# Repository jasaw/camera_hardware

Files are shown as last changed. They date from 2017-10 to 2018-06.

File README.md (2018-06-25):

# Raspberry Pi based security camera hardware

Outdoor Raspberry Pi Zero W security camera
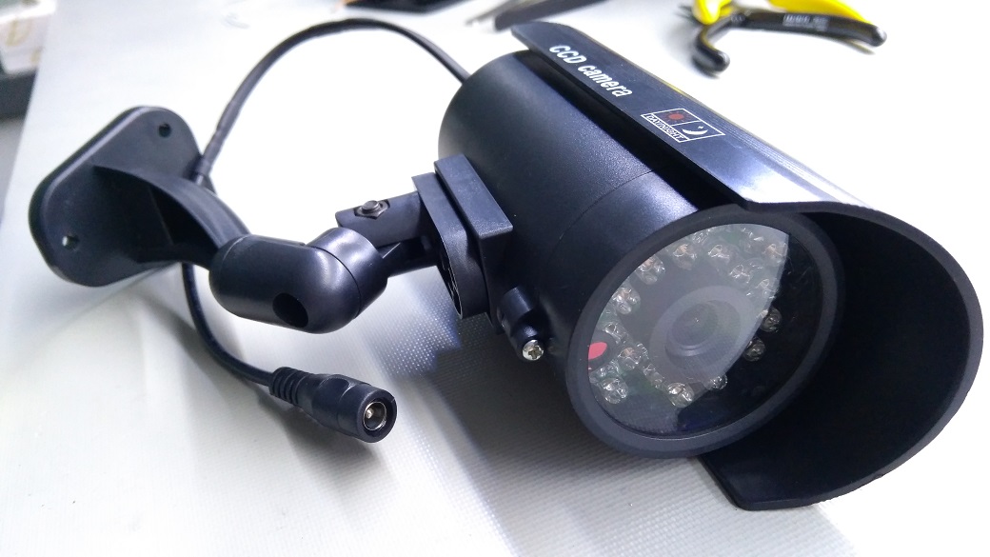
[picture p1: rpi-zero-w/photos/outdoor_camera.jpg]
outdoor_rpi_zero_w_cam


## Software

If you don't already have software to run on this camera, [motionEyeOS](https://github.com/jasaw/motioneyeos/releases) is a good one to try.

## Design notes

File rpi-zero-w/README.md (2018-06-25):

# Raspberry Pi Zero W security camera hardware

Outdoor Raspberry Pi Zero W security camera
outdoor_rpi_zero_w_cam

Exploded view of the camera parts.
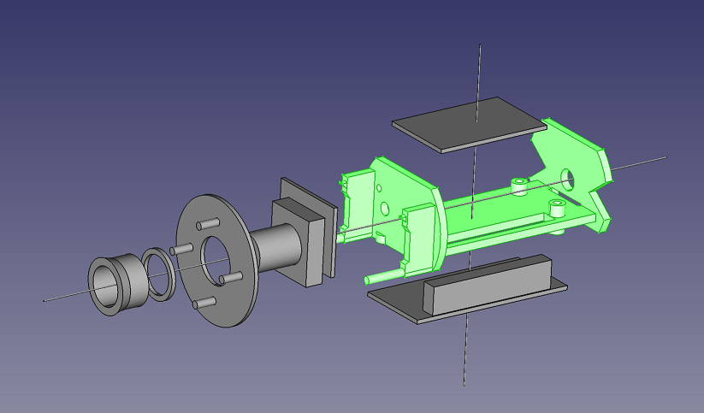
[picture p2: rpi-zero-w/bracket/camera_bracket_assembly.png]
assembly


## Bill of Materials

* Outdoor dummy security camera:
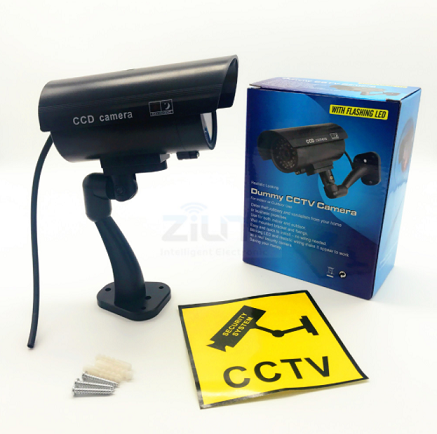
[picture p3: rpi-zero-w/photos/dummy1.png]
dummy1
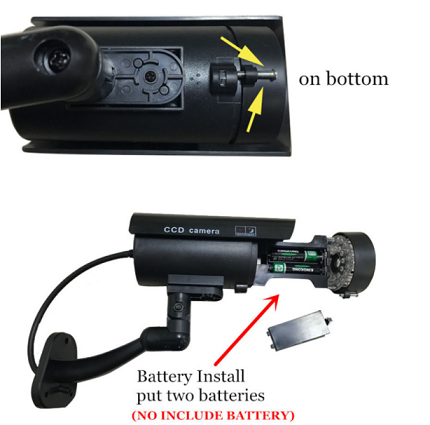
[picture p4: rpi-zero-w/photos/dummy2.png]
dummy2
  * 
  * Brand: zilnk
  * Model: D4
  * External dimensions: 117 x 117 x 65 mm
  * Internal dimensions: 103 x 48 mm
  * [AliExpress](https://www.aliexpress.com/item/Fake-Camera-Waterproof-Outdoor-Indoor-Security-Dummy-CCTV-Surveillance-Camera-Flashing-Rred-LED/32815686364.html)

* 3D printed camera bracket:
  * [Camera mounting bracket](bracket/README.md)

* 3D printed camera shroud:
  * [Camera shroud](bracket/camera_shroud.stl)

* 1.6mm foam tape

* Raspberry Pi NoIR Camera with IR-cut filter:
  * [AliExpress](https://www.aliexpress.com/item/Raspberry-Pi-Camera-IR-CUT-night-vision-noir-module-board-5mp-1080p-take-the-best-picture/32739395193.html)

* Raspberry Pi Zero camera FFC cable
  * [ebay](http://www.ebay.com.au/itm/New-Ribbon-FFC-Cable-Lead-Connection-Wire-For-Raspberry-Pi-Zero-V1-3-Camera/182720702738)
  * [ebay](http://www.ebay.com.au/itm/New-Ribbon-FFC-Cable-Wire-Line-Polyimide-For-Raspberry-Pi-Zero-V1-3-Camera/282571229898)

* Raspberry Pi Zero W without header

* 40-pin 0.1" pitch header for Raspberry Pi Zero W
  * Manufacturer part number: PREC020DAAN-RC
  * Digikey part number: S2012EC-20-ND
  * Alternate part number: PRPC020DAAN-RC

* microSD card

* Raspberry Pi Zero W PSU PCBA
  * [RPi Zero power supply PCBA](rpi-zero-psu/README.md)

* Camera IR-LED board
  * [IR-LED PCBA](camera-ir-led/README.md)

* 10cm 22AWG Male Female Connector JST Cable
    * [AliExpress](https://www.aliexpress.com/item/10-Pairs-100mm-10cm-Male-Female-Connector-JST-Plug-Cable-For-RC-BEC-Battery-Helicopter-DIY/32823944800.html)

* 12V DC Female Jack Connector Cable 5.5 X 2.1mm With 15CM Cable
    * [AliExpress](https://www.aliexpress.com/item/10pcs-12V-DC-Power-Plug-Female-Jack-Plug-Connector-Cable-5-5X2-1mm-With-Cord-Cable/32536715262.html)

* Minimum 12V 1A DC power supply with barrel connector
  * Barrel size: 5.5 x 2.1mm
  * [Jaycar - 12V DC 2.5A](https://www.jaycar.com.au/switchmode-mains-adaptor-12vdc-2-5a/p/MP3490)
  * [Little Bird Electronics - 12V DC 2.5A](https://www.littlebirdelectronics.com.au/switchmode-mains-adaptor-12vdc-2.5a)
  * [AliExpress - 12V DC power supply AU](https://www.aliexpress.com/item/Led-transformer-AC-110V-220V-to-12V-DC-EU-US-UK-AU-plug-Power-supply-12V/32702717419.html)
  * [AliExpress - 12V DC power supply AU](https://www.aliexpress.com/item/Power-Adapter-Supply-For-Led-Flexible-Tape-Light-AC110-220V-to-DC12V-1A-2A-3A-4A/32742445815.html)
  * [AliExpress - 12V DC power supply AU](https://www.aliexpress.com/item/LED-Driver-12V-1A-2A-3A-5A-6A-8A-10A-Power-Supply-AC-220V-to-12V/32821553829.html)

* 2 x 16mm M2.5 screws
  * [AliExpress](https://www.aliexpress.com/item/Cheap-Authentic-304-stainless-steel-Phillips-head-machine-screw-Phillips-pan-head-screws-M2-5-16/32368120946.html)

* 2 x M2.5 hex nuts
  * [AliExpress](https://www.aliexpress.com/item/Authentic-304-stainless-steel-hex-nuts-DIN934-hexagon-nut-M2-5/32359608962.html)

* 2 x 8mm M2 screws
  * [AliExpress](https://www.aliexpress.com/item/100PCS-Stainless-Steel-M2-x-8mm-Screw-Cross-Round-Head-Philips-Head-Screws-Hex-Socket-Button/32716321685.html)
  * [AliExpress](https://www.aliexpress.com/item/50x-Set-M2-Stainless-Steel-Screw-Thread-Diameter-304-8mm-2mm-Head-Shape-Cross-Screws-Round/32598285502.html)

* 2 x M2 hex nuts
  * [AliExpress](https://www.aliexpress.com/item/100pcs-din934-Stainless-Steel-304-M2-Hex-Nut/32763090222.html)

* (optional) 5.5*2.1mm DC 1 To 2 Way Jack Connector Power Splitter Cable
  * [AliExpress](https://www.aliexpress.com/item/2pcs-5-5-2-1mm-DC-1-To-2-Way-Jack-Connector-Power-Splitter-Cable-For/32845687591.html)

## Assembly Instructions

[Assembly instructions](README_assembly.md)

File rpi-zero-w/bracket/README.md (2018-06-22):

# 3D printed mounting bracket & camera shroud

3D printed mounting bracket for dummy camera enclosure. Only works with this [outdoor dummy camera](https://www.aliexpress.com/item/Fake-Camera-Waterproof-Outdoor-Indoor-Security-Dummy-CCTV-Surveillance-Camera-Flashing-Rred-LED/32815686364.html) enclosure.

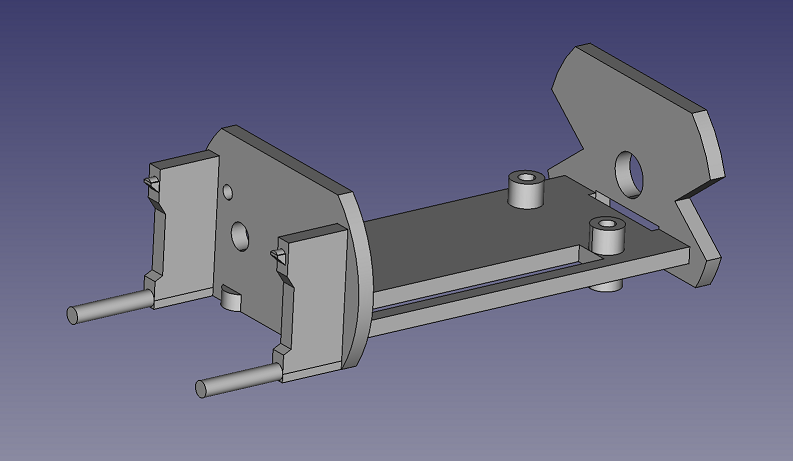
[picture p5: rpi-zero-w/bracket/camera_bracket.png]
bracket


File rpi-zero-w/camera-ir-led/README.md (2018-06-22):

# IR-LED board

IR-LED board for night vision.

Current issues:
* IR light is not bright enough to illuminate large area
  * As a workaround, use [external IR LEDs](https://www.aliexpress.com/item/Free-shipping-48LEDs-Illuminator-IR-Infrared-dome-CCTV-camera-hd-Night-enhancement-Fill-light-Vision-40M/32811672765.html).

### Design files

* [Gerbers](camera-ir-led-rev-1a.zip)
* [PCB top](camera-ir-led-rev-1a-top-parts.pdf)
* [PCB bottom](camera-ir-led-rev-1a-bottom-parts.pdf)

### Bill of Materials

* [BoM](camera-ir-led-rev-1a.xlsx)
* 5mm IR LEDs 940nm Wave Length
  * Forward Voltage: 1.5~1.6V
  * Forward Current: 60mA Continuous, 120mA peak 10% pulse width
  * View Angle: 15-30 degree
  * [ebay](https://www.ebay.com.au/itm/100pcs-5mm-LED-Lights-Infrared-Emitters-IR-Emitting-Diodes-940nm-Wave-Length/201201649166)
* 5mm IR LEDs 850nm Wave Length
  * Forward Voltage: 1.45~1.65V
  * Forward Current: 20mA Continuous, 100mA max pulse
  * View Angle: 30 degree
  * [AliExpress](https://www.aliexpress.com/item/100Pcs-5mm-IR-Led-850nm-Lamp-Transmitting-Tube-Emitting-Diode-Infrared-LED-Diode-ir-850nm-High/32373548361.html)
* GL5528 LDR Photo Resistors
  * [ebay](http://www.ebay.com.au/itm/20PCS-Photoresistor-GL5528-LDR-Photo-Resistors-Light-Dependent-WS/222122787897)
* JST PH 2.00mm pitch 4-pin connector and cable
  * [AliExpress](https://www.aliexpress.com/item/20-Sets-PH-2-0mm-JST-2-3-4-5-6-7-8-9-10-12P/32782287584.html)
  * [AliExpress](https://www.aliexpress.com/item/20-SETS-Mini-Micro-JST-2-0-PH-4-Pin-Connector-plug-with-Wires-Cables-300MM/32611300648.html)
  * [AliExpress](https://www.aliexpress.com/item/10sets-1-0mm-1-25mm-1-5mm-2-0-2-54mm-2-3-4-5-6/32733307616.html)
* Optical IR Cut Light Filter 8mm (for LDR light sensor)
  * [ebay](https://www.ebay.com.au/itm/10pcs-Optical-UV-IR-Cut-Light-Filter-Blocking-For-Camera-Astronomy-Lens-8mm-Slim/282653207704)
* Some heatshrink to hold the IR Cut Light Filter

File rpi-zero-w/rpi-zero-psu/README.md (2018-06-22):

# Raspberry Pi Zero power supply

Power supply board that plugs directly onto a Raspberry Pi Zero (W)

Features:
* Input: 9V to 24V DC
* Output: 5V 3A to the RPi
* Basic light sensor circuit ([LDR reader software here](https://github.com/jasaw/ldr-reader))
* One GPIO controlled output (5V 1A)

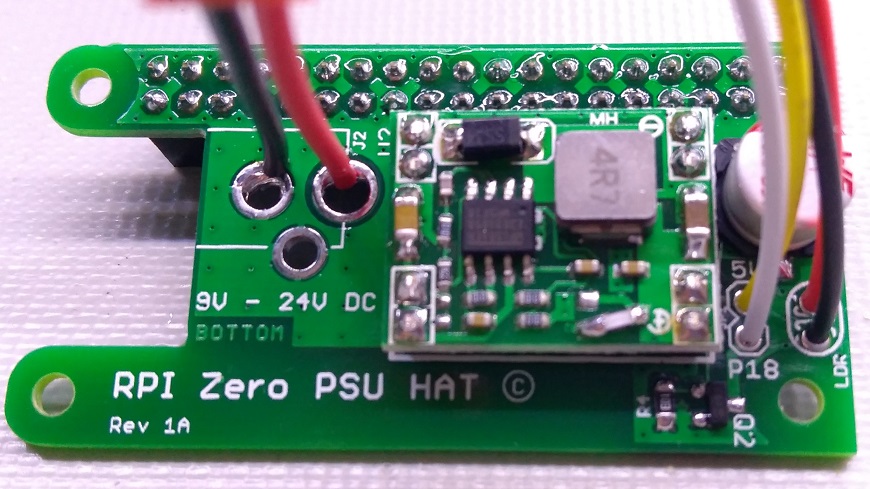
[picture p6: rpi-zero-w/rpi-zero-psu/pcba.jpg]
PCBA


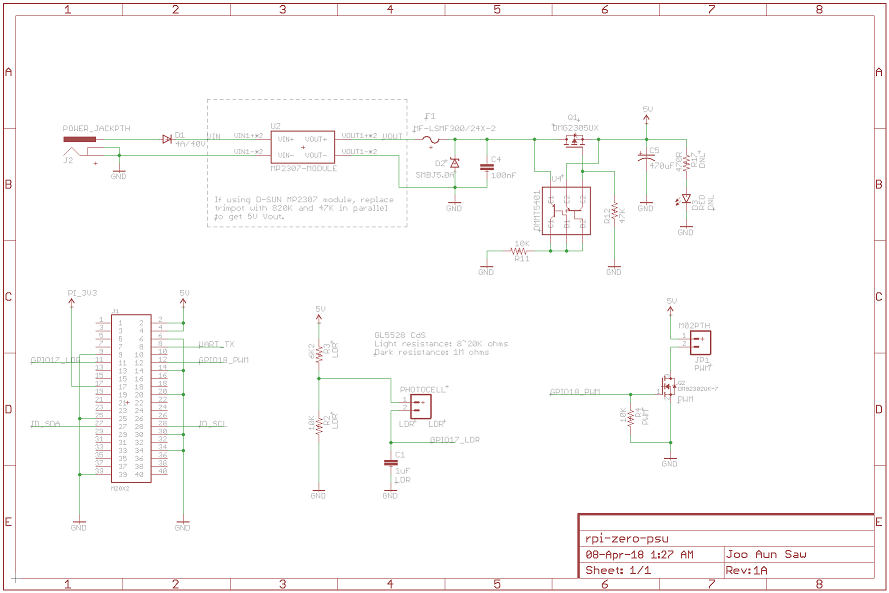
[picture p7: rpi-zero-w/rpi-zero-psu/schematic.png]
schematic


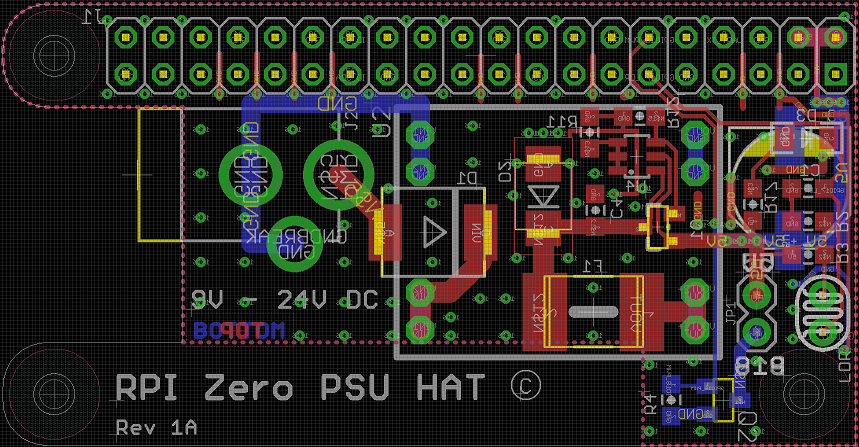
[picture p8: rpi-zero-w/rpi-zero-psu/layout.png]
layout


### Design files

* [Gerbers](rpi-zero-psu-rev-1a.zip)
* [PCB top](rpi-zero-psu-rev-1a-top.pdf)
* [PCB bottom](rpi-zero-psu-rev-1a-bottom.pdf)

### Bill of Materials

* [BoM](rpi-zero-psu-rev-1a-bom.pdf)
* 3A XM1584 DC-DC step-down module can be sourced from other places:
  * [Seeed Studio](https://www.seeedstudio.com/Adjustable-Step-Down-DC%26DC-Converter-%280.8V-18V%263A%29-p-1716.html)
  * [AliExpress](https://www.aliexpress.com/item/Free-Shipping-5PCS-XM1584-Ultra-small-size-DC-DC-step-down-power-supply-module-3A-adjustable/32262690691.html)
  * [AliExpress](https://www.aliexpress.com/item/10pcs-lot-Ultra-Small-Size-DC-DC-Step-Down-Power-Supply-Module-3A-Adjustable-Step-Down/32478748937.html)

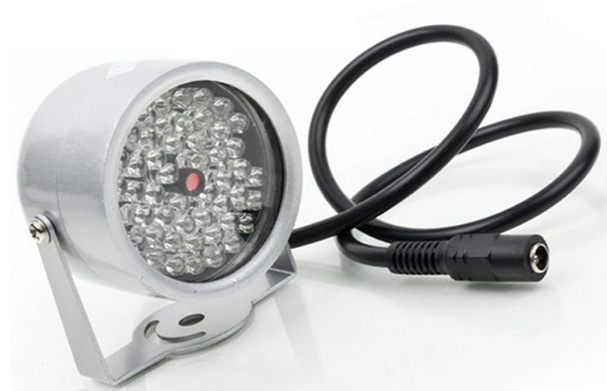
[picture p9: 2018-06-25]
rpi-zero-w/photos/external_ir_led.png

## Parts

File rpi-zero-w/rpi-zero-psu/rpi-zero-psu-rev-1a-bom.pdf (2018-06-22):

Qty Value | Parts | Description | DIGIKEY | MOUSER | PARTNO
1 DMG2302UK-7 | Q2 | N-Channel Mosfet | DMG2302UK-7DICT-ND | 621-DMG2302UK-7 | DMG2302UK-7
1 100nF | C4 | Capacitor | 478-1395-1-ND | 581-08055C104K | 08055C104KAT2A
1 10K | R2 | Resistor | 311-10KARCT-ND | 603-RC0805JR-0710KL | RC0805JR-0710KL
1 10K | R4 | Resistor | 311-10KARCT-ND | 603-RC0805JR-0710KL | RC0805JR-0710KL
1 10K | R11 | Resistor | 311-10KARCT-ND | 603-RC0805JR-0710KL | RC0805JR-0710KL
1 1uF | C1 | Capacitor | 311-1456-1-ND | 603-CC805KKX7R8BB105 CC0805KKX7R8BB105
1 470uF | C5 | Capacitor Polarized | 732-6443-1-ND | 710-875115150005 | 875115150005
1 47K | R12 | Resistor | 311-47.0KCRCT-ND | 603-RC0805FR-0747KL | RC0805FR-0747KL
1 4A/40V | D1 | Diode | MBRS340T3GOSCT-ND | 863-MBRS340T3G | MBRS340T3G
1 6K2 | R3 | Resistor | 311-6.2KARCT-ND | 603-RC0805JR-076K2L | RC0805JR-076K2L
1 DMG2305UX | Q1 | P-Channel Mosfet | DMG2305UX-7DICT-ND | 621-DMG2305UX-7 | DMG2305UX-7
1 DMMT5401 | U4 | Matched PNP Small Signal Transistor. DMMT5401-FDICT-ND | 621-DMMT5401-7-F | DMMT5401-7-F
1 M20X2 | J1 | 40-pin female header 0.1" pitch | S7123-ND | 517-929975-01-20 | PPPC202LFBN-RC
1 MF-LSMF300/24X-2 F1 | PTC fuse | MF-LSMF300/24X-2CT-ND 652-MF-LSMF300/24X-2 MF-LSMF300/24X-2
1 MP2307-MODULE U2 | DC-DC buck converter module | 106990005-ND | 713-106990005 | 106990005
1 POWER_JACKPTH | J2 | Power Jack | CP-002A-ND | 490-PJ-002A | PJ-002A
1 SMBJ5.0A | D2 | Zener Diode | SMBJ5.0ALFCT-ND | 576-SMBJ5.0A | SMBJ5.0A

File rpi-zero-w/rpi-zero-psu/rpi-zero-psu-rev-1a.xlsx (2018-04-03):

Qty | Value | Package | Parts | Description | DNL | LDR | PWM | DIGIKEY | MOUSER | PARTNO | ALT_PARTNO
1 | DMG2302UK-7 | SOT23 | Q2 | N-Channel Mosfet |  |  | 1 | DMG2302UK-7DICT-ND | 621-DMG2302UK-7 | DMG2302UK-7
1 | 100nF | 805 | C4 | Capacitor |  |  |  | 478-1395-1-ND | 581-08055C104K | 08055C104KAT2A
1 | 10K | 805 | R2 | Resistor |  | 1 |  | 311-10KARCT-ND | 603-RC0805JR-0710KL | RC0805JR-0710KL
1 | 10K | 805 | R4 | Resistor |  |  | 1 | 311-10KARCT-ND | 603-RC0805JR-0710KL | RC0805JR-0710KL
1 | 10K | 805 | R11 | Resistor |  |  |  | 311-10KARCT-ND | 603-RC0805JR-0710KL | RC0805JR-0710KL
1 | 1uF | 805 | C1 | Capacitor |  | 1 |  | 311-1456-1-ND | 603-CC805KKX7R8BB105 | CC0805KKX7R8BB105
1 | 470R | 805 | R17 | Resistor | 1 |  |  | 311-470ARCT-ND | 603-RC0805JR-07470RL | RC0805JR-07470RL
1 | 470uF | PANASONIC_F | C5 | Capacitor Polarized |  |  |  | 732-6443-1-ND | 710-875115150005 | 875115150005 | EEE-1CA471UP
1 | 47K | 805 | R12 | Resistor |  |  |  | 311-47.0KCRCT-ND | 603-RC0805FR-0747KL | RC0805FR-0747KL
1 | 4A/40V | SMC | D1 | Diode |  |  |  | MBRS340T3GOSCT-ND | 863-MBRS340T3G | MBRS340T3G
1 | 6K2 | 805 | R3 | Resistor |  | 1 |  | 311-6.2KARCT-ND | 603-RC0805JR-076K2L | RC0805JR-076K2L
1 | DMG2305UX | SOT-23 | Q1 | P-Channel Mosfet |  |  |  | DMG2305UX-7DICT-ND | 621-DMG2305UX-7 | DMG2305UX-7
1 | DMMT5401 | SOT23-6 | U4 | Matched PNP Small Signal Transistor. |  |  |  | DMMT5401-FDICT-ND | 621-DMMT5401-7-F | DMMT5401-7-F
1 | M02PTH | 1X02 | JP1 | Standard 2-pin 0.1 header |  |  | 1 |  | 571-826936-2 | 826936-2
1 | M20X2 | 2X20 | J1 | 40-pin female header 0.1" pitch |  |  |  | S7123-ND | 517-929975-01-20 | PPPC202LFBN-RC
1 | MF-LSMF300/24X-2 | 2920 | F1 | PTC fuse |  |  |  | MF-LSMF300/24X-2CT-ND | 652-MF-LSMF300/24X-2 | MF-LSMF300/24X-2
1 | MP2307-MODULE | MP1584EN-MODULE | U2 | DC-DC buck converter module |  |  |  | 106990005-ND | 713-106990005 | 106990005 | IM130731001
1 | PHOTOCELL | 1X02_NO_SILK | LDR | Photo resistor |  | 1 |  |  |  | GL5528
1 | POWER_JACKPTH | POWER_JACK_PTH | J2 | Power Jack |  |  |  | CP-002A-ND | 490-PJ-002A | PJ-002A
1 | RED | LED-1206 | D3 | Red LED | 1 |  |  | 160-1167-1-ND | 859-LTST-C150CKT | LTST-C150CKT
1 | SMBJ5.0A | SMB-DIODE | D2 | Zener Diode |  |  |  | SMBJ5.0ALFCT-ND | 576-SMBJ5.0A | SMBJ5.0A

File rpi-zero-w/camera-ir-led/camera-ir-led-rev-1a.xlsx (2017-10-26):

Qty | Value | Device | Package | Parts | Description | DIGIKEY | MOUSER | PARTNO
8 | 10R | RESISTOR0805-RES | 805 | R2, R3, R4, R5, R6, R7, R8, R17 | Resistor | 311-10ARCT-ND | 603-RC0805JR-0710RL | RC0805JR-0710RL
24 | IR | LED5MM | LED5MM | D1, D2, D3, D4, D5, D6, D7, D8, D9, D10, D11, D12, D13, D14, D15, D16, D17, D18, D19, D20, D21, D22, D23, D24 | LEDs
1 | JST-PH-4 | CONNECTOR-4-POS-THJST-PH-4 | JST-PH-4-POS-TH | J1 | 4-pin JST PH 2.0mm pitch
1 | PHOTOCELLPTH | PHOTOCELLPTH | PHOTOCELL | R1 | CdS photoresistor |  |  | GL5528

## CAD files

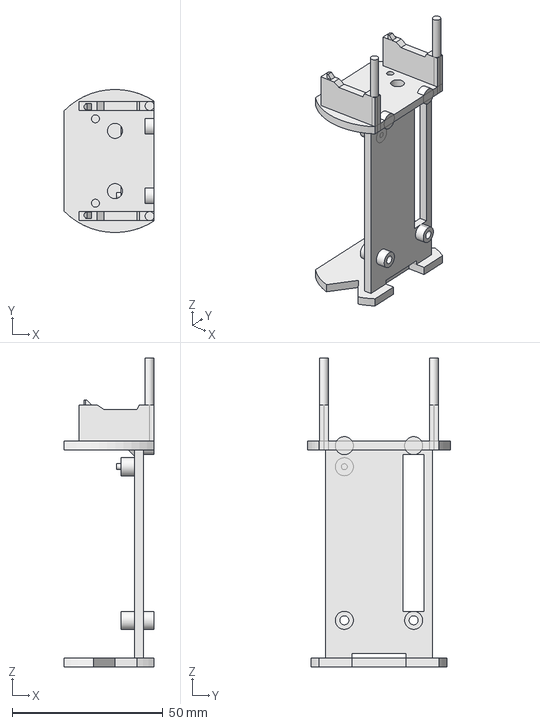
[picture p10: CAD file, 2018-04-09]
rpi-zero-w/bracket/camera_bracket.FCStd
30.0 x 47.5 x 102.6 mm

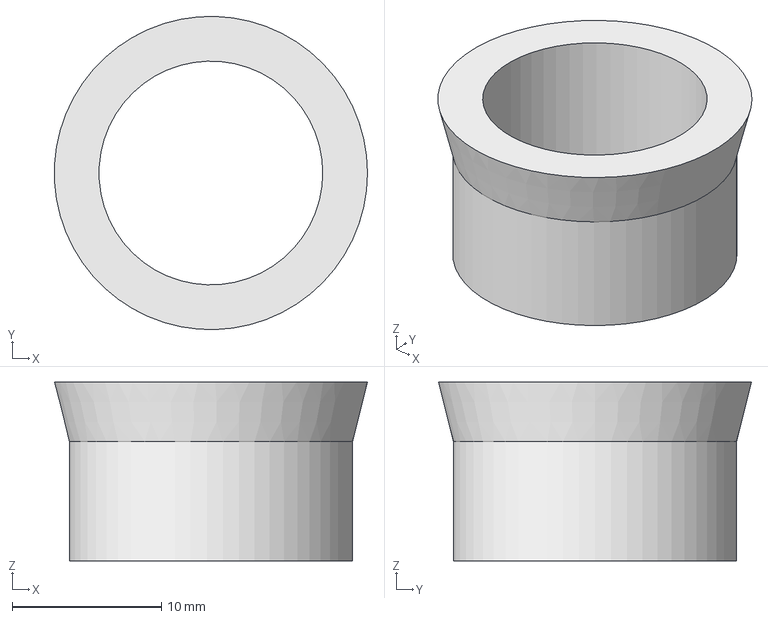
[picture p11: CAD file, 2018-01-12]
rpi-zero-w/bracket/camera_shroud.FCStd
21.0 x 21.0 x 12.0 mm

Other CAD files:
rpi-zero-w/bracket/camera_bracket.stl
rpi-zero-w/bracket/camera_shroud.stl

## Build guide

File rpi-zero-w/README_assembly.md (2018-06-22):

# Raspberry Pi Zero W security camera hardware assembly instructions

1. Solder a male 40-pin connector on the underside of the RPi Zero W.

2. Cut the foam tape into an O-ring shape and stick it at the bottom of the 3D printed camera shroud.

3. Mount the camera module onto the 3D printed bracket and secure it using two M2 screws and nuts.

4. Insert the IR-LED board.

5. Prepare all the parts required to install onto the 3D printed bracket.
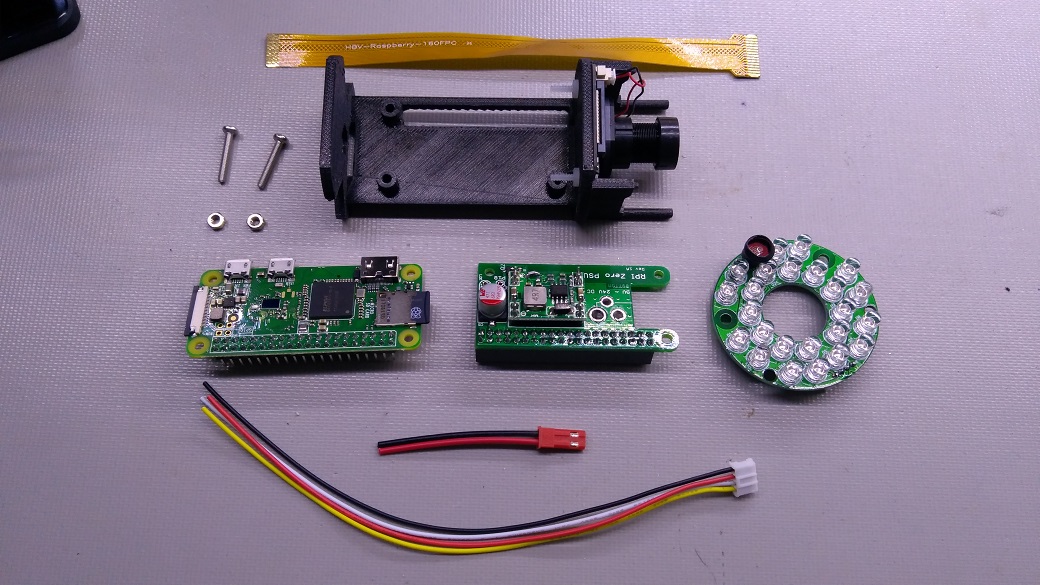
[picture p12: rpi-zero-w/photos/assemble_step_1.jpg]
step 1
   

6. Solder power cable and 4-wire cable onto the RPi Zero power supply PCBA.
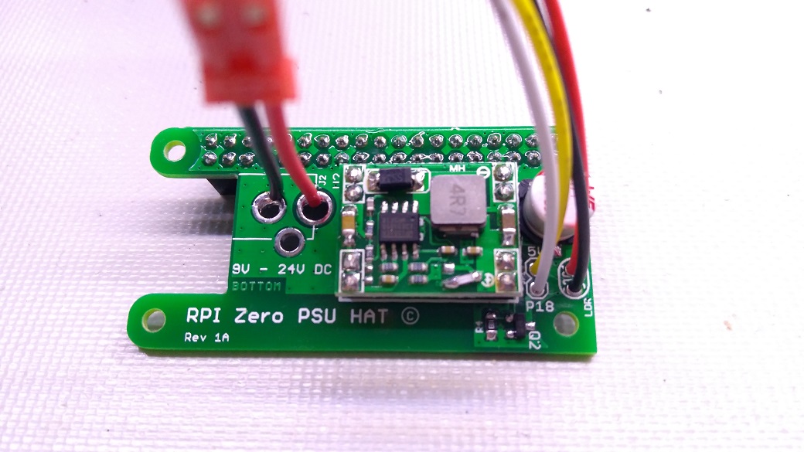
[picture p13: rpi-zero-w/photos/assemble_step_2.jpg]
step 2
   

7. Connect the FFC camera cable to the RPi Zero W and loop it through the bracket.
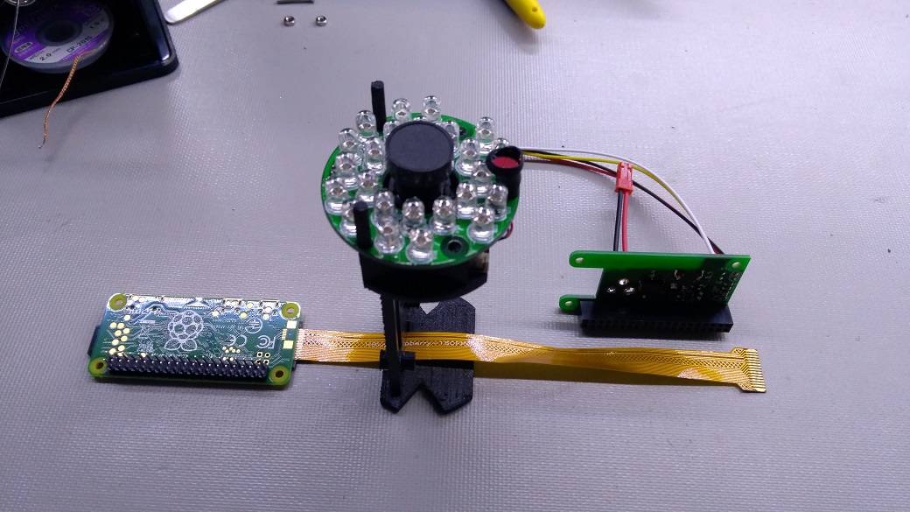
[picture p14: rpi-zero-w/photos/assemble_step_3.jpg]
step 3
   

8. Connect the FFC camera cable to the camera module. Mount the RPi Zero W and power supply PCBA together with the 3D printed bracket in between. Secure the boards using two M2.5 screws and nuts.
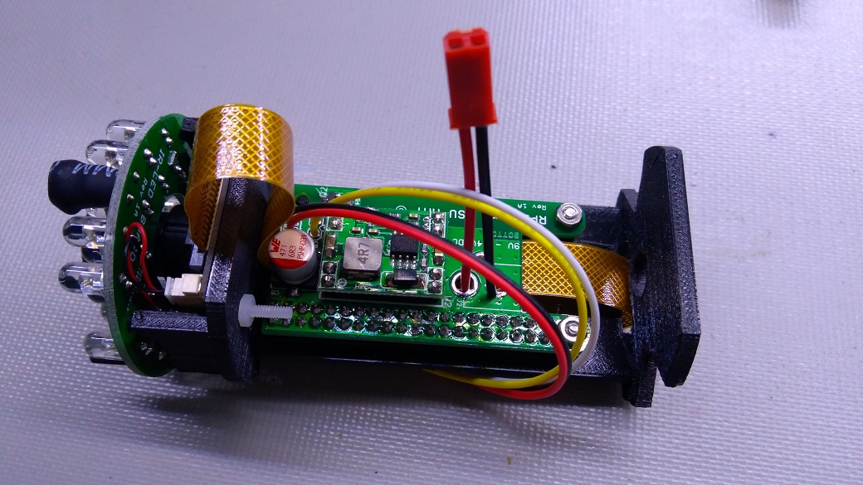
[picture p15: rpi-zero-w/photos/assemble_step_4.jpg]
step 4
   

9. Connect the 4-wire cable to the IR-LED board.
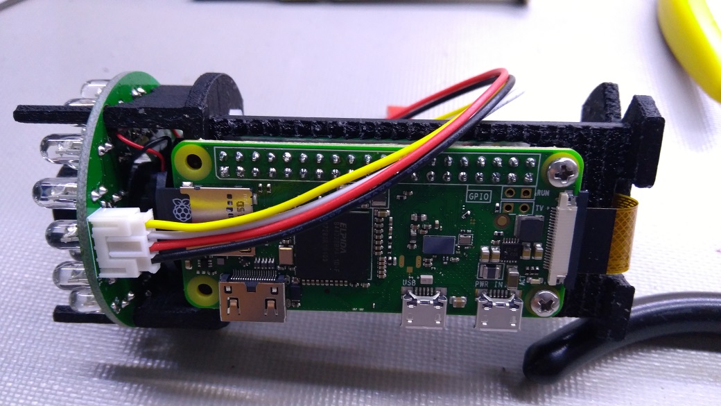
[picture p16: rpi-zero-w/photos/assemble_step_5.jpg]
step 5
   

10. Disassemble the dummy camera and prepare the cables required.
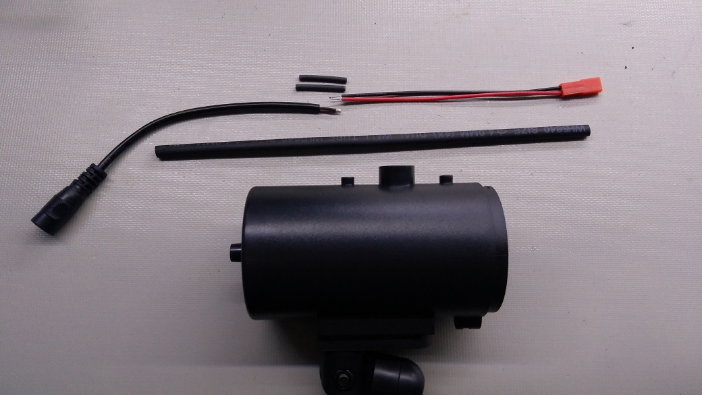
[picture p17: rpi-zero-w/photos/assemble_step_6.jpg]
step 6
    

11. Insert the heatshrink over the wires then loop the power cable through the hole at the back of the dummy camera case. Solder the power cables together and use heatshrink over the cable.
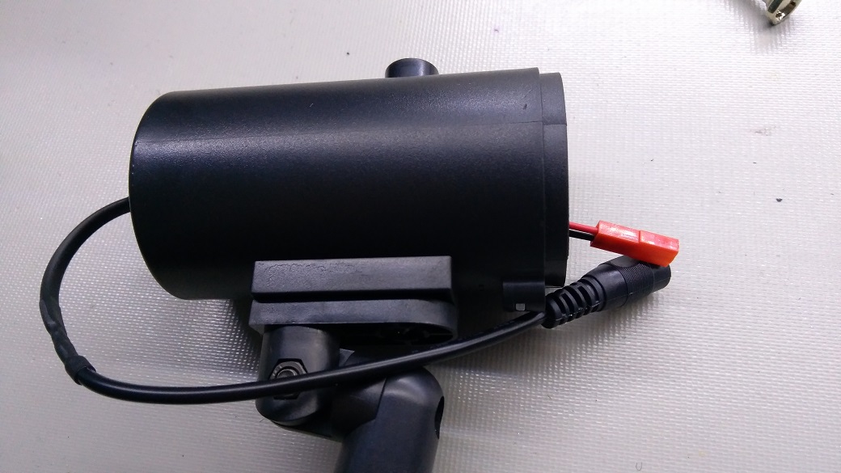
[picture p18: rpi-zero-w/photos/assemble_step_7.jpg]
step 7
    

12. Insert the assembled 3D printed bracket into the dummy camera case, insert the camera shroud, and close it. Done.
    step 8

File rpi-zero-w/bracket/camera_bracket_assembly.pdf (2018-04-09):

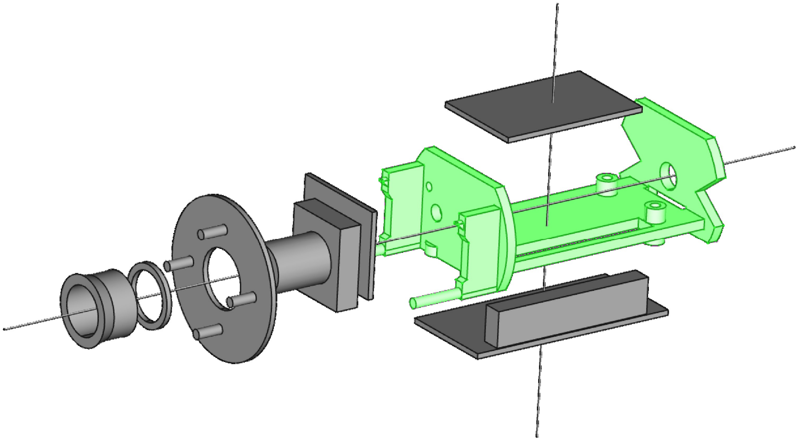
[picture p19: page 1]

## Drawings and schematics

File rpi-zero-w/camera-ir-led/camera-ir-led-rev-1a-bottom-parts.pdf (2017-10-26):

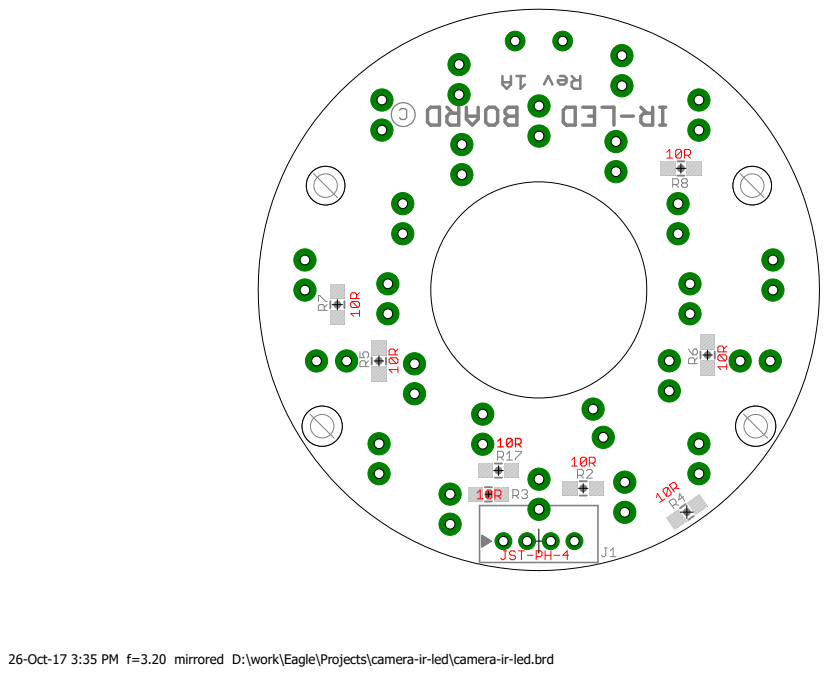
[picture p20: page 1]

26-Oct-17 3:35 PM f=3.20 mirrored D:\work\Eagle\Projects\camera-ir-led\camera-ir-led.brd

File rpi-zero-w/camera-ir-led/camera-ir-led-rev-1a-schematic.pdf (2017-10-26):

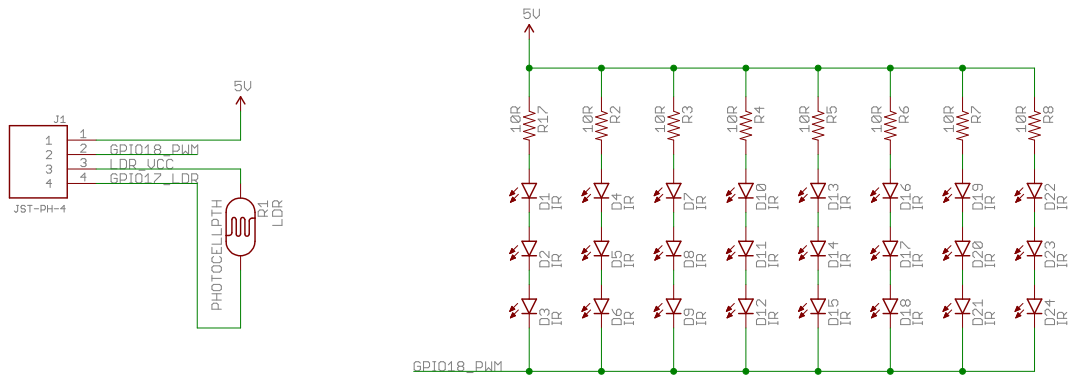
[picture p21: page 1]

26-Oct-17 3:36 PM D:\work\Eagle\Projects\camera-ir-led\camera-ir-led.sch (Sheet: 1/1)

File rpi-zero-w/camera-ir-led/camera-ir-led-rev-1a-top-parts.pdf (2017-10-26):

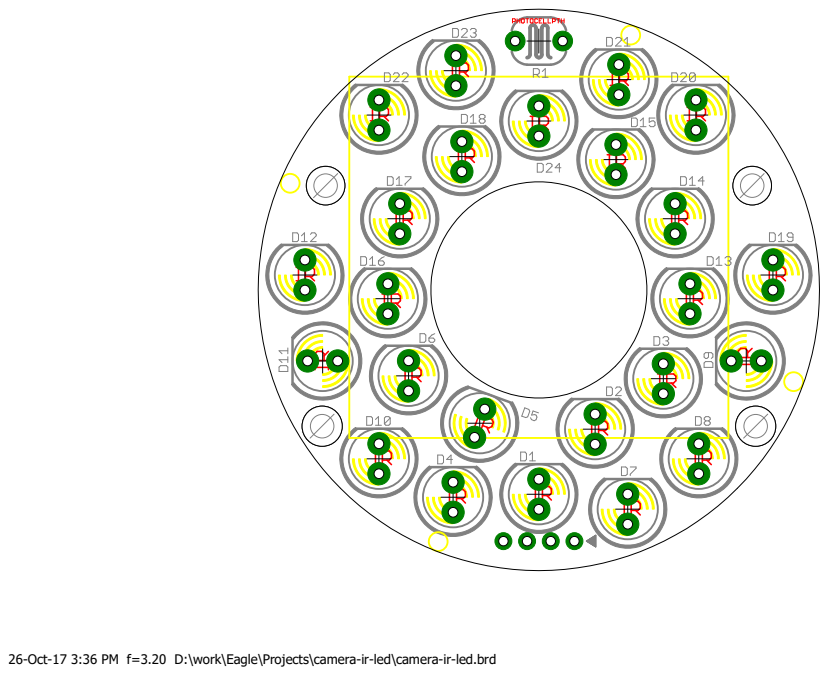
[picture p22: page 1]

26-Oct-17 3:36 PM f=3.20 D:\work\Eagle\Projects\camera-ir-led\camera-ir-led.brd

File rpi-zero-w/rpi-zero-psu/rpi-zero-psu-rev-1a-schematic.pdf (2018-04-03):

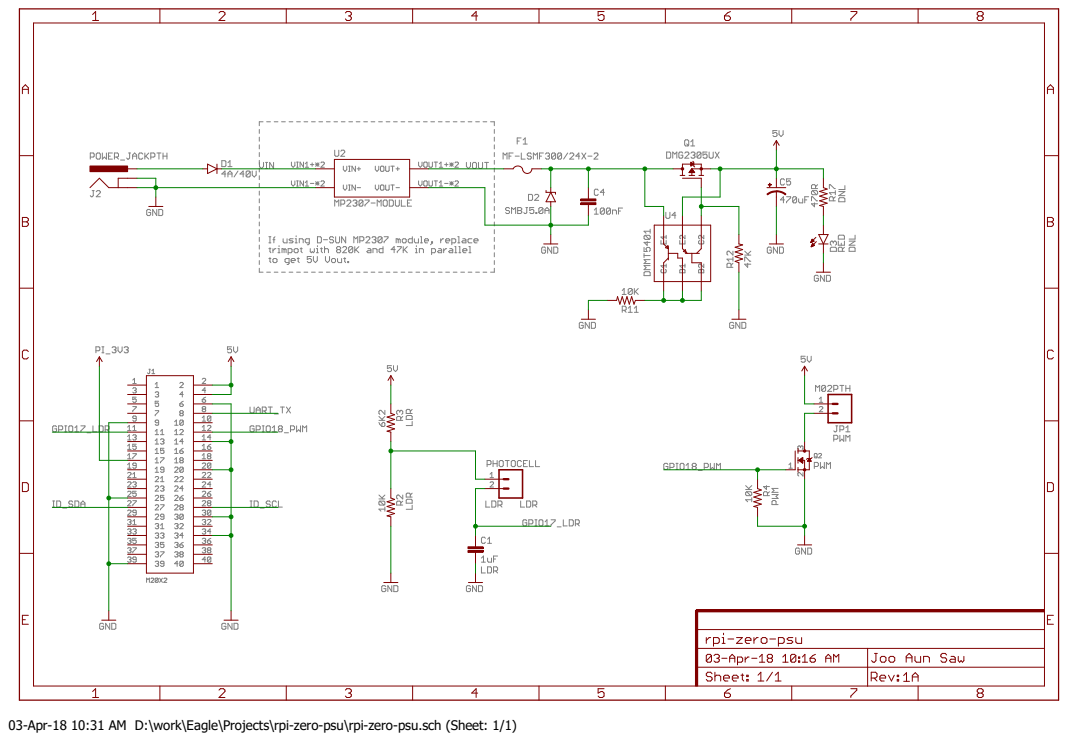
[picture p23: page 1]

03-Apr-18 10:31 AM D:\work\Eagle\Projects\rpi-zero-psu\rpi-zero-psu.sch (Sheet: 1/1)

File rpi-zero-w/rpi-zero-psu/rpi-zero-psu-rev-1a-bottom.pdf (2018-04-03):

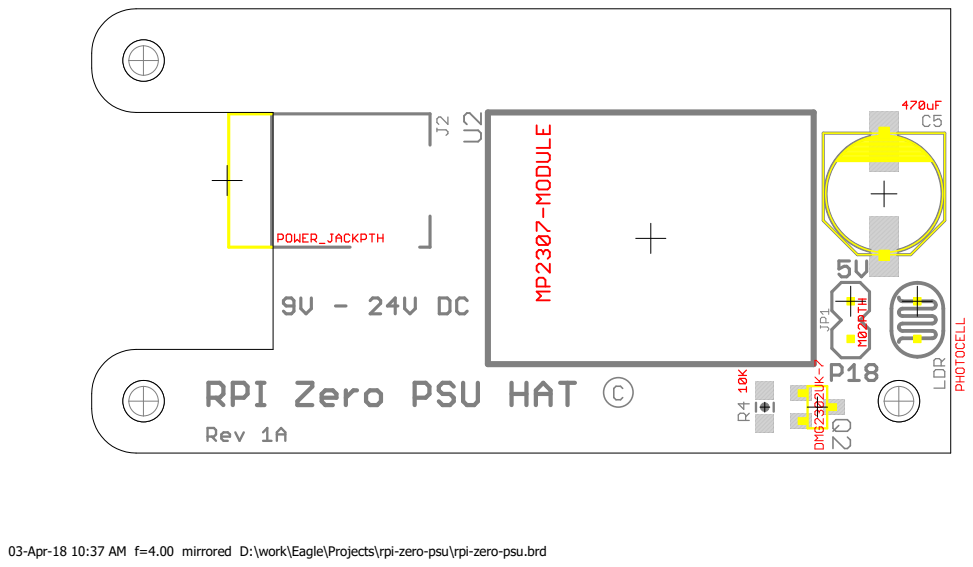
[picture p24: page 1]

03-Apr-18 10:37 AM f=4.00 mirrored D:\work\Eagle\Projects\rpi-zero-psu\rpi-zero-psu.brd

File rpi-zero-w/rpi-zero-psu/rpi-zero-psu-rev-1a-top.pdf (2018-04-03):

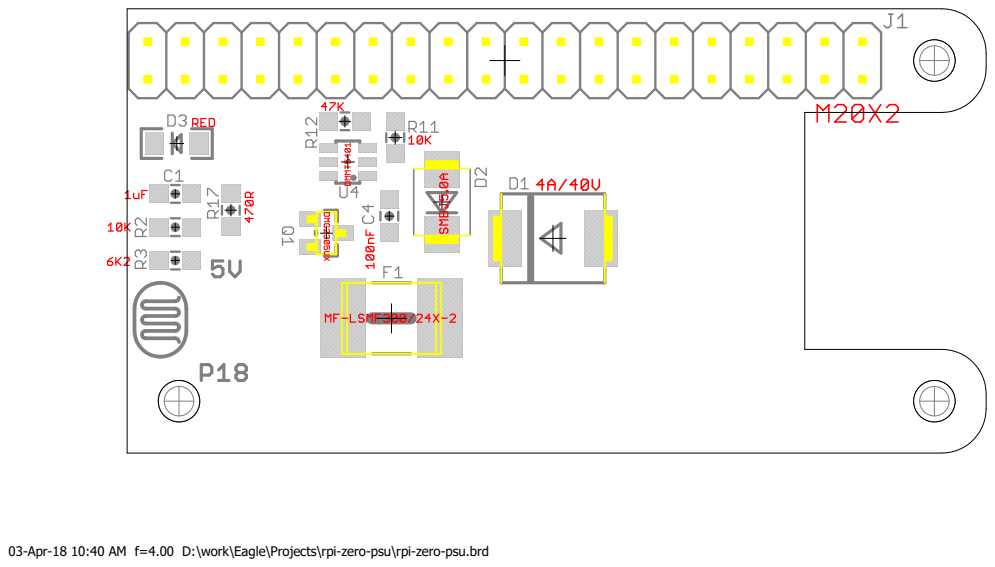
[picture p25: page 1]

03-Apr-18 10:40 AM f=4.00 D:\work\Eagle\Projects\rpi-zero-psu\rpi-zero-psu.brd

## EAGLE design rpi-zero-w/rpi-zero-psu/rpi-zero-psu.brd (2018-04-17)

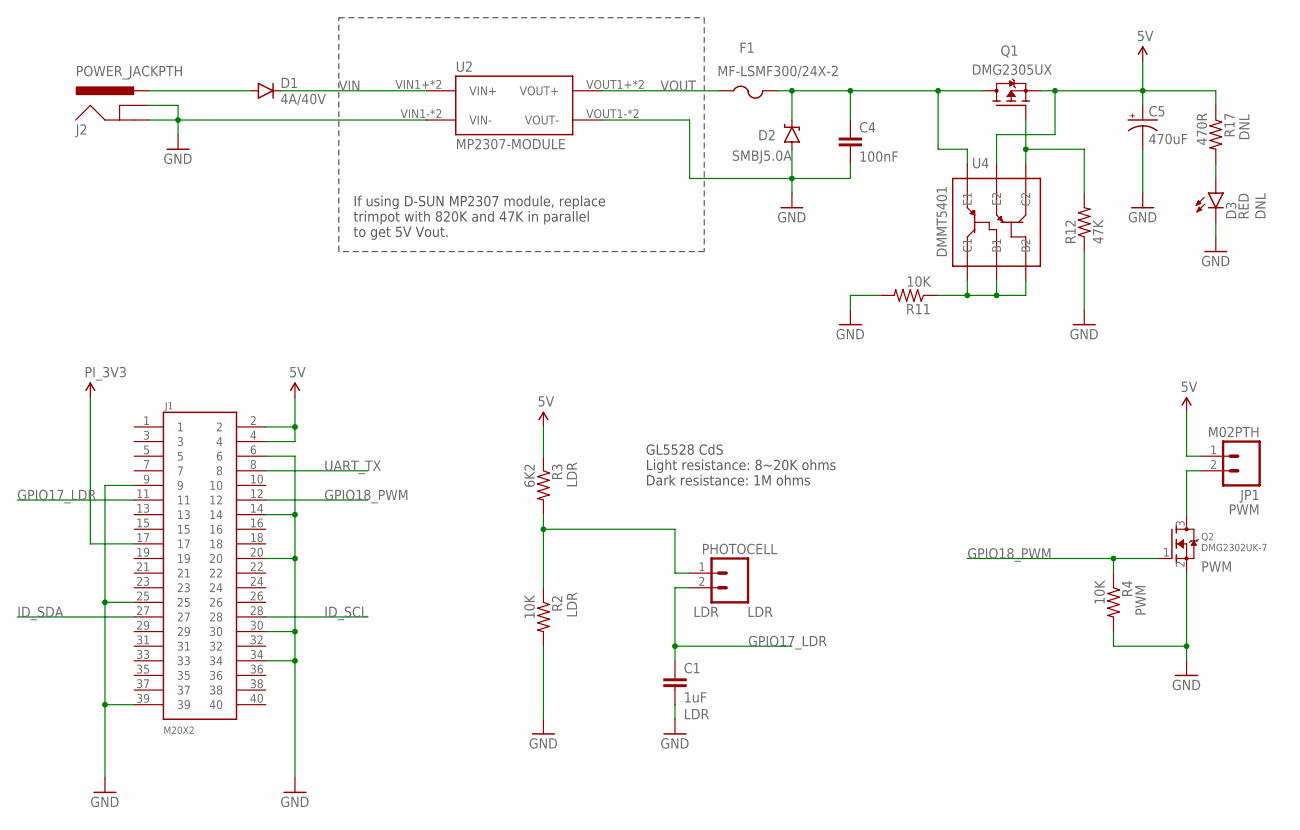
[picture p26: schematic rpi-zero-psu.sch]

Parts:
C1: 1uF; 0805; PARTNO CC0805KKX7R8BB105; DIGIKEY 311-1456-1-ND
C4: 100nF; 0805; PARTNO 08055C104KAT2A; DIGIKEY 478-1395-1-ND
C5: 470uF; PANASONIC_F; PARTNO 875115150005; DIGIKEY 732-6443-1-ND
D1: 4A/40V; SMC; PARTNO MBRS340T3G; DIGIKEY MBRS340T3GOSCT-ND
D2: SMBJ5.0A; SMB-DIODE; PARTNO SMBJ5.0A; DIGIKEY SMBJ5.0ALFCT-ND
D3: RED; LED-1206; PARTNO LTST-C150CKT; DIGIKEY 160-1167-1-ND
F1: MF-LSMF300/24X-2; 2920; PARTNO MF-LSMF300/24X-2; DIGIKEY MF-LSMF300/24X-2CT-ND
J1: M20X2; 2X20; PARTNO PPPC202LFBN-RC; DIGIKEY S7123-ND
J2: POWER_JACKPTH; POWER_JACK_PTH; PARTNO PJ-002A; DIGIKEY CP-002A-ND
JP1: M02PTH; 1X02; PARTNO 826936-2; MOUSER 571-826936-2
LDR: PHOTOCELL; 1X02_NO_SILK
Q1: DMG2305UX; SOT-23; PARTNO DMG2305UX-7; DIGIKEY DMG2305UX-7DICT-ND
Q2: DMG2302UK-7; SOT23; PARTNO DMG2302UK-7; DIGIKEY DMG2302UK-7DICT-ND
R2, R4, R11: 10K; 0805; PARTNO RC0805JR-0710KL; DIGIKEY 311-10KARCT-ND
R3: 6K2; 0805; PARTNO RC0805JR-076K2L; DIGIKEY 311-6.2KARCT-ND
R12: 47K; 0805; PARTNO RC0805FR-0747KL; DIGIKEY 311-47.0KCRCT-ND
R17: 470R; 0805; PARTNO RC0805JR-07470RL; DIGIKEY 311-470ARCT-ND
U2: MP2307-MODULE; MP1584EN-MODULE; PARTNO 106990005; DIGIKEY 106990005-ND
U4: DMMT5401; SOT23-6; PARTNO DMMT5401-7-F; DIGIKEY DMMT5401-FDICT-ND

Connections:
3.3V: J1.17
5V: C5.+, J1.2, J1.4, JP1.1, Q1.2 (S), R3.1, R17.1, U4.5 (E2)
GND: C1.2, C4.2, C5.-, D2.A, D3.C, J1.6, J1.9, J1.14, J1.20, J1.25, J1.30, J1.34, J1.39, J2.GND, J2.GNDBREAK, Q2.2 (S), R2.2, R4.2, R11.2, R12.1, U2.VIN1- (VIN-), U2.VIN2- (VIN-), U2.VOUT1- (VOUT-), U2.VOUT2- (VOUT-)
GPIO17_LDR: C1.1, J1.11, LDR.2
GPIO18_PWM: J1.12, Q2.1 (G), R4.1
ID_SCL: J1.28
ID_SDA: J1.27
unnamed: JP1.2, Q2.3 (D)
unnamed: LDR.1, R2.1, R3.2
unnamed: D3.A, R17.2
unnamed: D1.A, J2.PWR
unnamed: C4.1, D2.C, F1.2, Q1.3 (D), U4.6 (E1)
unnamed: R11.1, U4.1 (C1), U4.2 (B1), U4.3 (B2)
unnamed: Q1.1 (G), R12.2, U4.4 (C2)
UART_TX: J1.8
VIN: D1.C, U2.VIN1+ (VIN+), U2.VIN2+ (VIN+)
VOUT: F1.1, U2.VOUT1+ (VOUT+), U2.VOUT2+ (VOUT+)

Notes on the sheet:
If using D-SUN MP2307 module, replace trimpot with 820K and 47K in parallel to get 5V Vout.
GL5528 CdS Light resistance: 8~20K ohms Dark resistance: 1M ohms

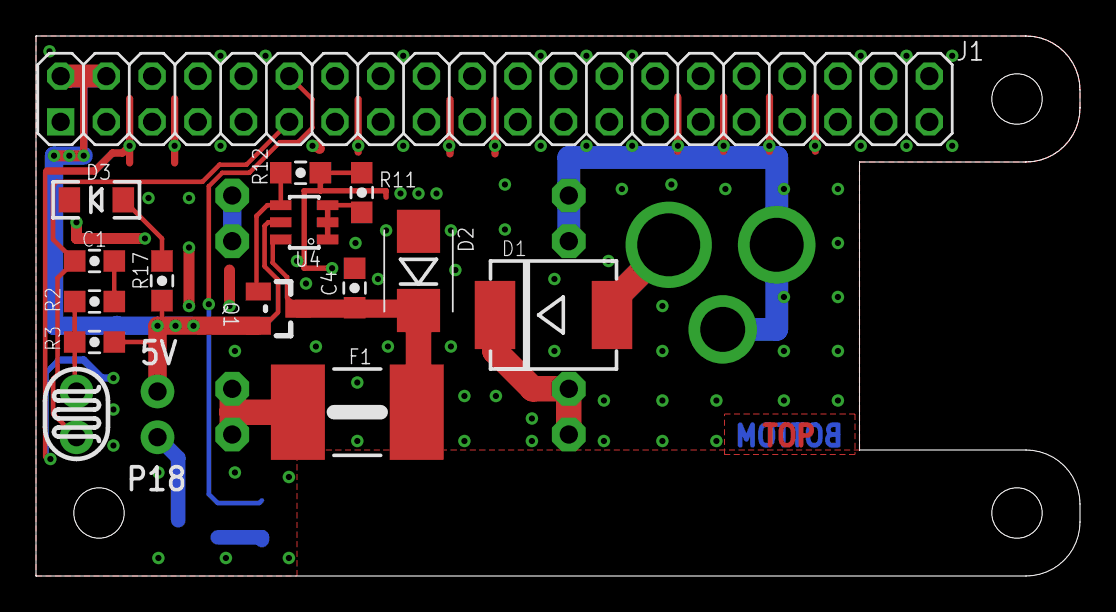
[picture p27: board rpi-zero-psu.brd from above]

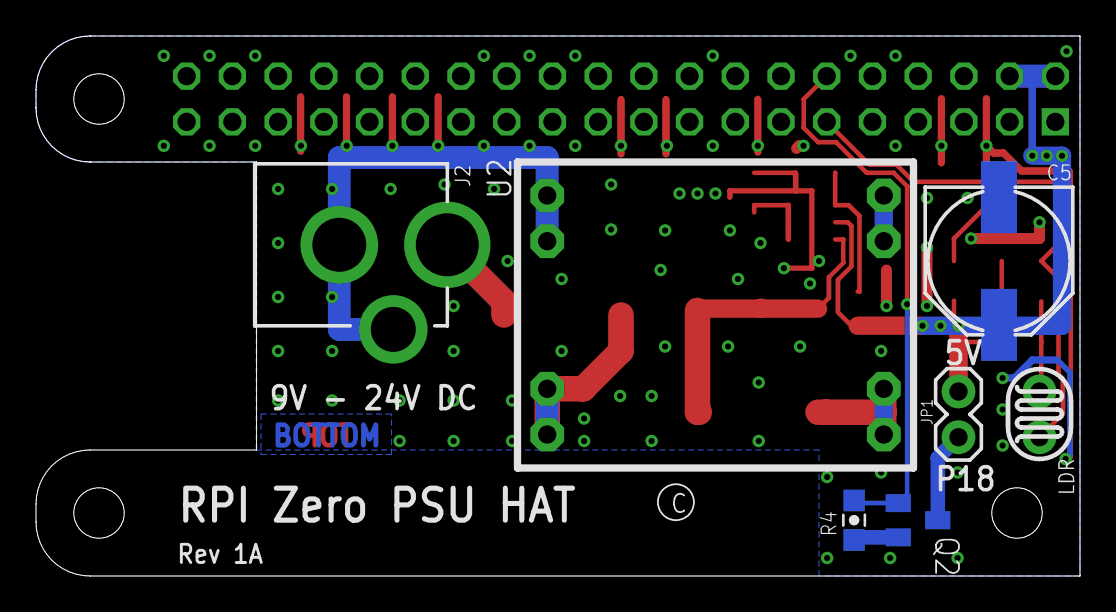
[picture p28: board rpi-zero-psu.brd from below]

Board: 2 copper layers, 58.0 x 30.0 mm, 21 parts (7 on the bottom side), 13 nets.

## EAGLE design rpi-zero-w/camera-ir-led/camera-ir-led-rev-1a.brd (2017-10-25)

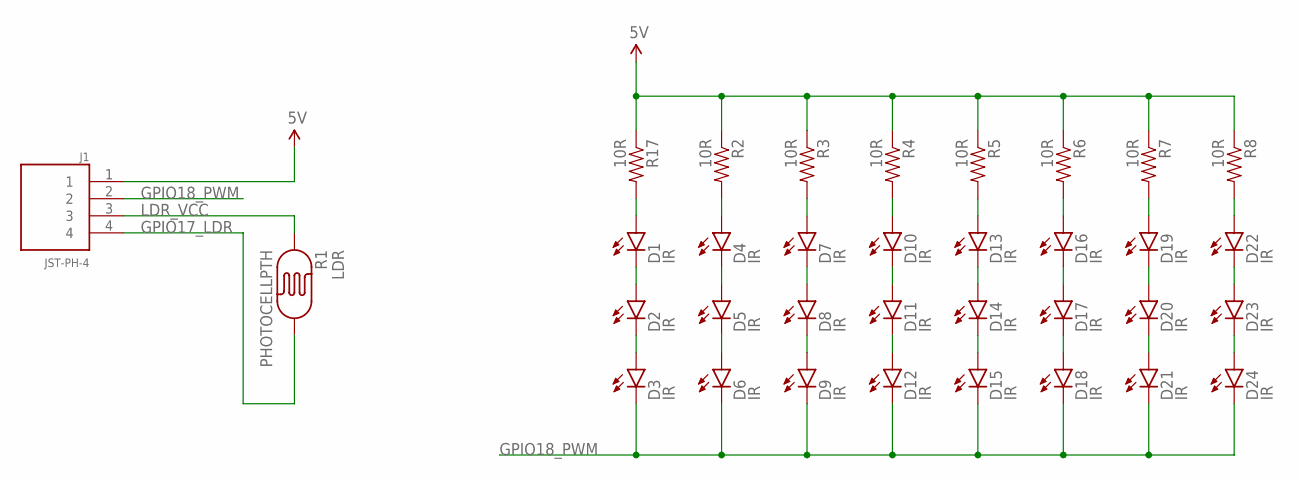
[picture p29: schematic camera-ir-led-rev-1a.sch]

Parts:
D1, D2, D3, D4, D5, D6, D7, D8, D9, D10, D11, D12, D13, D14, D15, D16, D17, D18, D19, D20, D21, D22, D23, D24: IR; LED5MM
J1: JST-PH-4; JST-PH-4-POS-TH
R1: PHOTOCELLPTH; PHOTOCELL; PARTNO GL5528
R2, R3, R4, R5, R6, R7, R8, R17: 10R; 0805; PARTNO RC0805JR-0710RL; DIGIKEY 311-10ARCT-ND

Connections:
5V: J1.1, R2.1, R3.1, R4.1, R5.1, R6.1, R7.1, R8.1, R17.1
GPIO17_LDR: J1.4, R1.2
GPIO18_PWM: D3.K (C), D6.K (C), D9.K (C), D12.K (C), D15.K (C), D18.K (C), D21.K (C), D24.K (C), J1.2
LDR_VCC: J1.3, R1.1
unnamed: D2.K (C), D3.A
unnamed: D1.K (C), D2.A
unnamed: D1.A, R17.2
unnamed: D5.K (C), D6.A
unnamed: D4.K (C), D5.A
unnamed: D4.A, R2.2
unnamed: D8.K (C), D9.A
unnamed: D7.K (C), D8.A
unnamed: D7.A, R3.2
unnamed: D11.K (C), D12.A
unnamed: D10.K (C), D11.A
unnamed: D10.A, R4.2
unnamed: D14.K (C), D15.A
unnamed: D13.K (C), D14.A
unnamed: D13.A, R5.2
unnamed: D17.K (C), D18.A
unnamed: D16.K (C), D17.A
unnamed: D16.A, R6.2
unnamed: D20.K (C), D21.A
unnamed: D19.K (C), D20.A
unnamed: D19.A, R7.2
unnamed: D23.K (C), D24.A
unnamed: D22.K (C), D23.A
unnamed: D22.A, R8.2

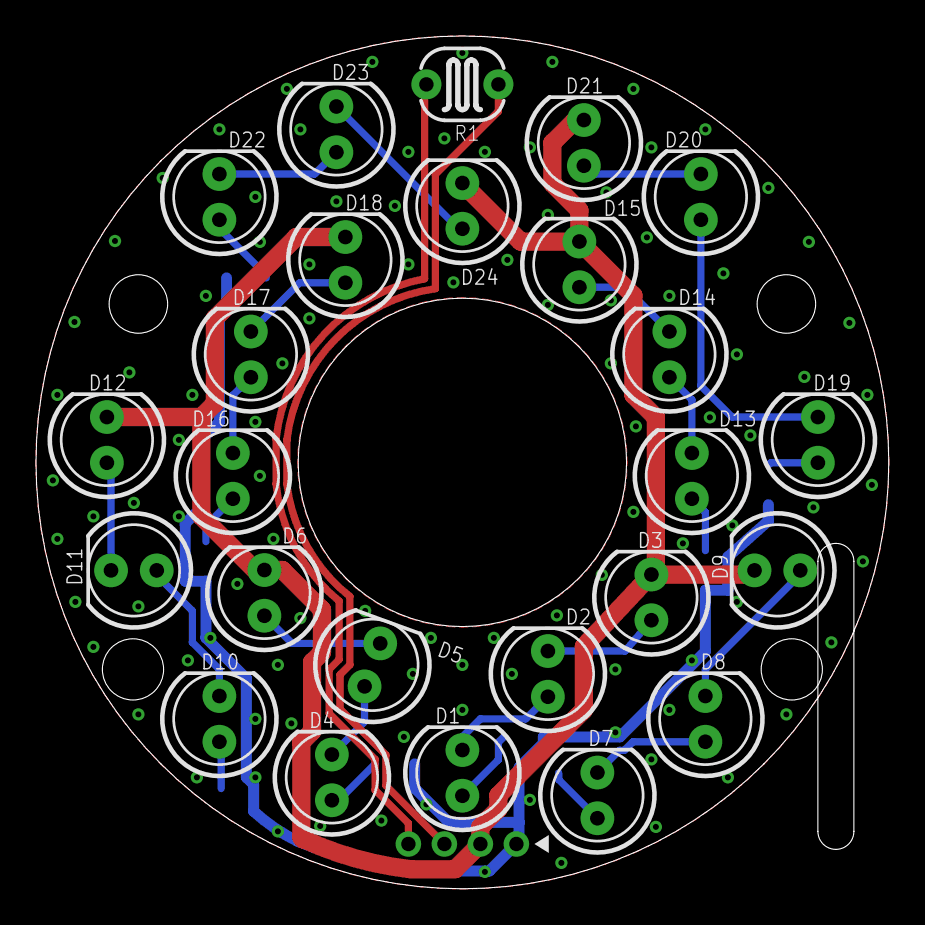
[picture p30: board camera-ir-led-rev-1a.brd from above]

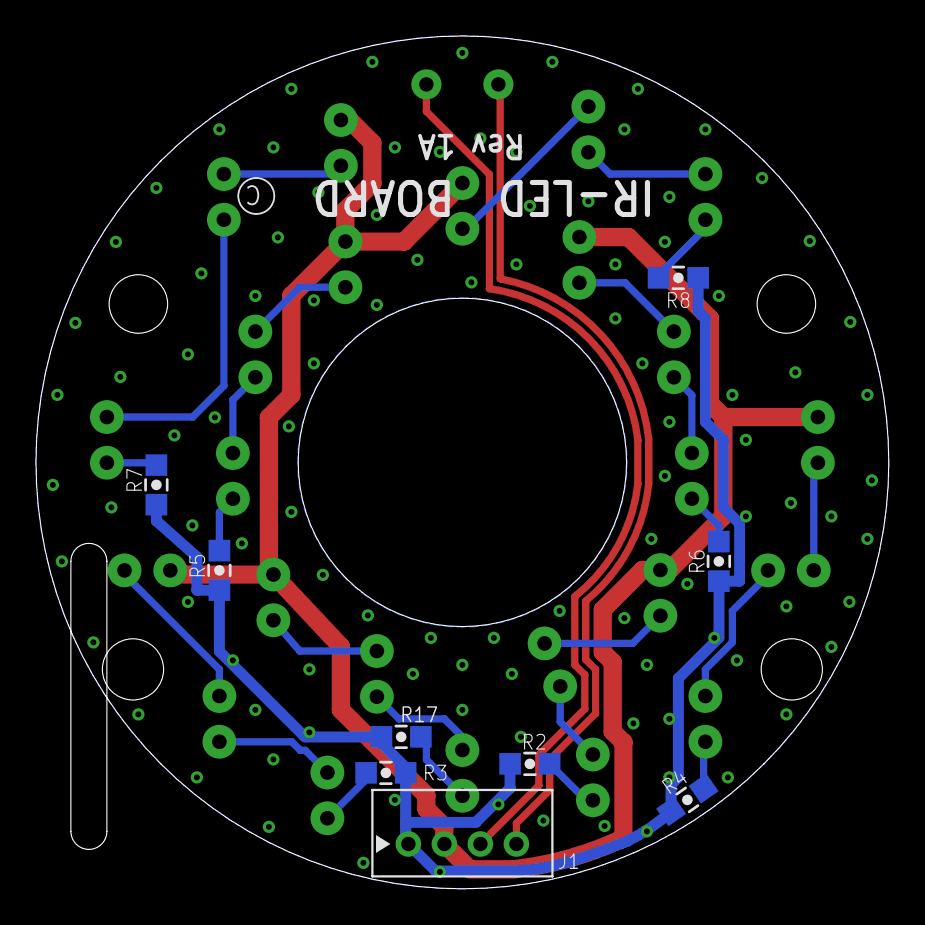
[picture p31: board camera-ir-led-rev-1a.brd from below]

Board: 2 copper layers, 47.4 x 47.4 mm, 34 parts (9 on the bottom side), 28 nets.

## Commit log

2017-10-20 add rpi zero w camera bracket
    [camera_bracket.FCStd, camera_bracket.stl]
2017-10-24 add IR LED board
    [camera-ir-led.brd, camera-ir-led.sch]
2017-10-25 moved IR LEDs
    [camera-ir-led.brd]
2017-10-26 add rev 1 gerbers
    [camera-ir-led-rev-1a.brd, camera-ir-led-rev-1a.sch, camera-ir-led-rev-1a.xlsx]
2018-01-12 add camera shroud 3D model
    [camera_shroud.FCStd, camera_shroud.stl]
2018-03-27 modified camera bracket for rpi-zero-psu
    [camera_bracket.FCStd, camera_bracket.stl]
2018-03-27 camera bracket: improve IR board mount
    [camera_bracket.FCStd, camera_bracket.stl]
2018-03-28 camera bracket: add UM2 normal quality gcode
2018-04-03 add rpi-zero power supply hat
    [rpi-zero-psu-rev-1a.xlsx, rpi-zero-psu.brd, rpi-zero-psu.sch]
2018-04-09 added camera shroud model into bracket design
    [camera_bracket.FCStd]
2018-04-09 add camera shroud foam model
    [camera_bracket.FCStd]
2018-04-09 add assembly diagram
2018-04-17 rpi-zero-psu: removed milling layer
    [rpi-zero-psu.brd, rpi-zero-psu.sch]
2018-06-22 Updated documentation
    [camera_bracket.FCStd, camera_bracket.stl, camera_shroud.FCStd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]

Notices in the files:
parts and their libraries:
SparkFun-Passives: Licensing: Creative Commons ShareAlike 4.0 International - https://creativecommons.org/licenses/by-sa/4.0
